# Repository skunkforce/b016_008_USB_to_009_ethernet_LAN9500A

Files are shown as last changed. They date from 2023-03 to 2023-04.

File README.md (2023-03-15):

# edgy_board number b016
This design is part of the [edgy board project](https://github.com/skunkforce/edgy_boards).

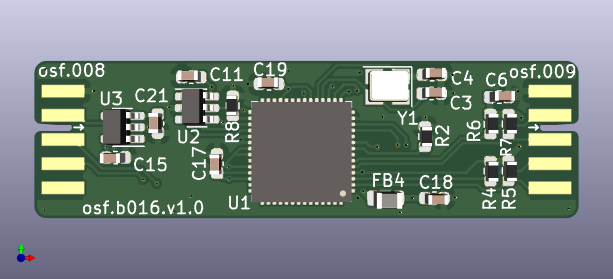
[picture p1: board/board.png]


# getting started
This repository uses submodules. After cloning use the command 

```$ git submodule update --init --recursive```

to pull the submodules before opening the project with kicad. 

# Tests
Tests can be found in [TESTS.md](TESTS.md)

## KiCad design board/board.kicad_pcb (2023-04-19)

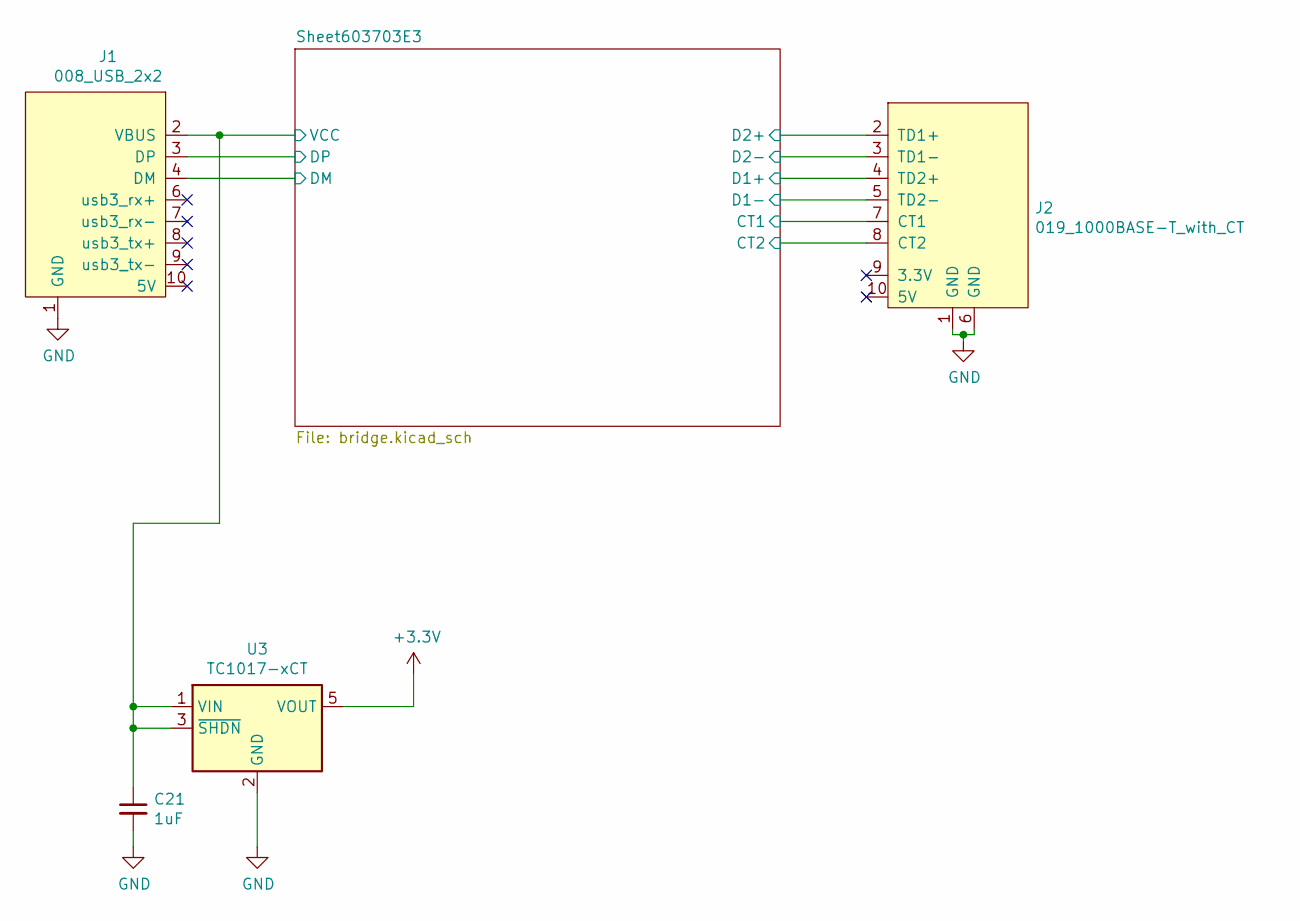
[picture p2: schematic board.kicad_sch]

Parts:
C21: 1uF; C_0603_1608Metric
J1: 008_USB_2x2; on_edge_2x05_device
J2: 019_1000BASE-T_with_CT; on_edge_2x05_host
U3: TC1017-xCT; SOT-23-5

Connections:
+3.3V: U3.5 (VOUT); also elsewhere on the board
/Sheet603703E3/CT1: J2.7 (CT1), J2.8 (CT2); also elsewhere on the board
/Sheet603703E3/D1+: J2.4 (TD2+); also elsewhere on the board
/Sheet603703E3/D1-: J2.5 (TD2-); also elsewhere on the board
/Sheet603703E3/D2+: J2.2 (TD1+); also elsewhere on the board
/Sheet603703E3/D2-: J2.3 (TD1-); also elsewhere on the board
/Sheet603703E3/DM: J1.4 (DM); also elsewhere on the board
/Sheet603703E3/DP: J1.3 (DP); also elsewhere on the board
/VCC: C21.1, J1.2 (VBUS), U3.1 (VIN), U3.3 (~SHDN)
GND: C21.2, J1.1 (GND), J2.1 (GND), J2.6 (GND), U3.2 (GND); also elsewhere on the board

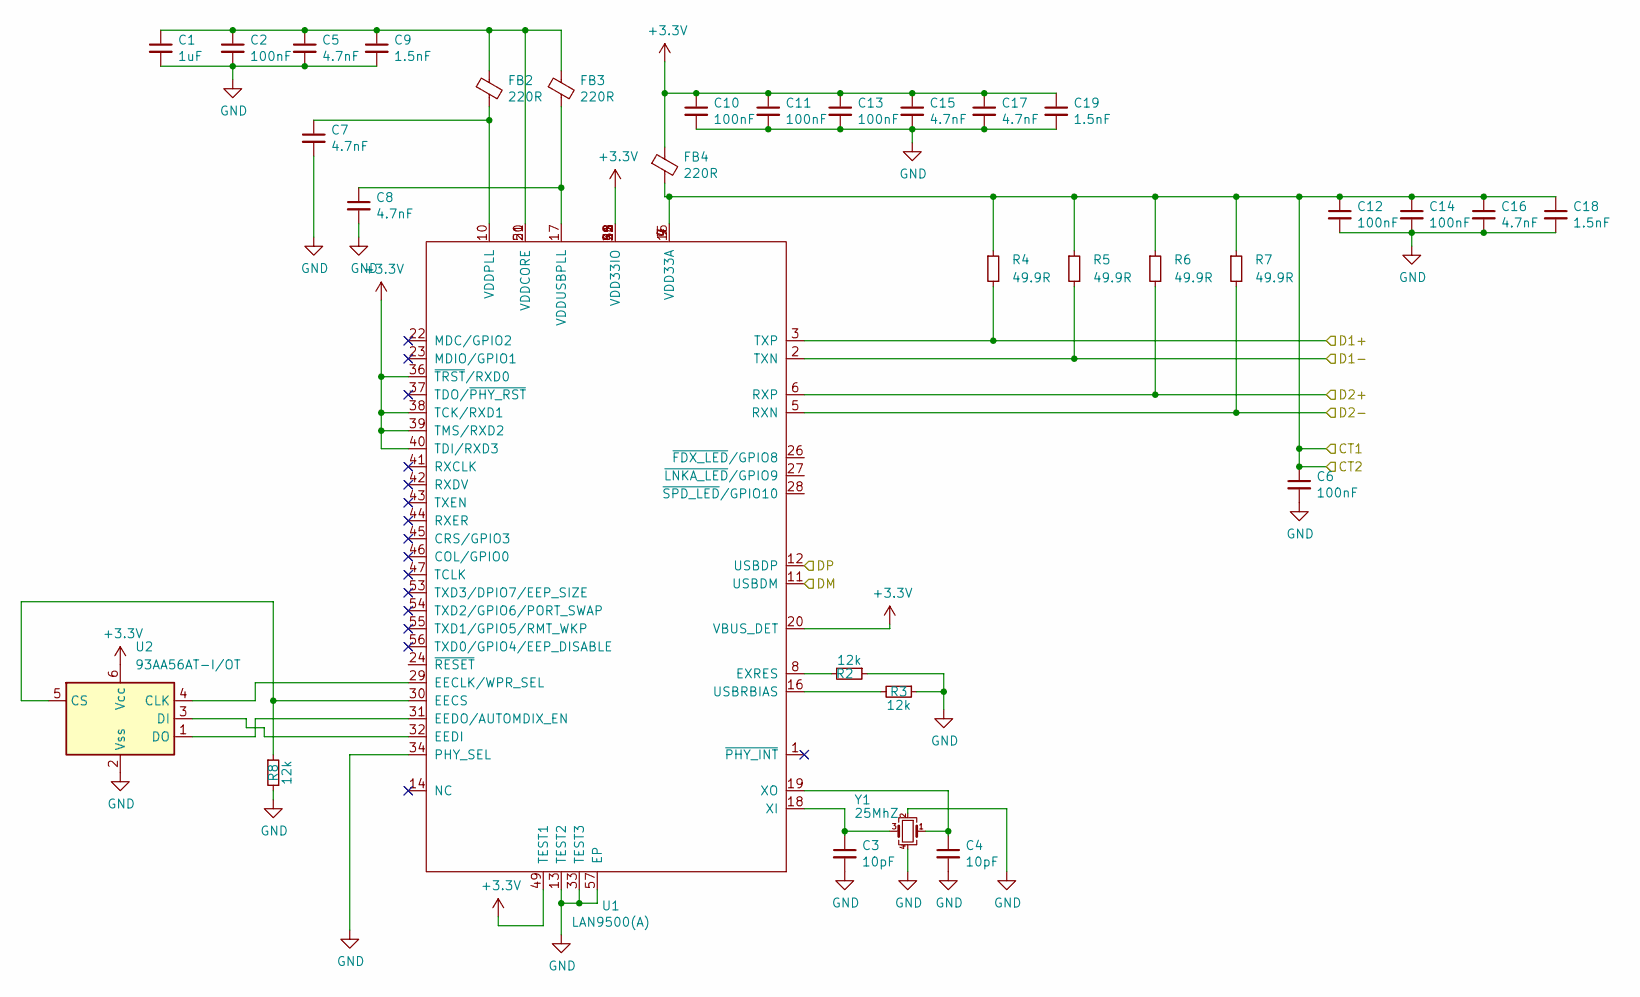
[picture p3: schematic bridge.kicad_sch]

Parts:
C1: 1uF; C_0603_1608Metric
C2, C6, C10, C11, C12, C13, C14: 100nF; C_0603_1608Metric
C3, C4: 10pF; C_0603_1608Metric
C5, C7, C8, C15, C16, C17: 4.7nF; C_0603_1608Metric
C9, C18, C19: 1.5nF; C_0603_1608Metric
FB2, FB3, FB4: 220R; L_0805_2012Metric
R2, R3, R8: 12k; R_0603_1608Metric
R4, R5, R6, R7: 49.9R; R_0603_1608Metric
U1: LAN9500(A); QFN-56-1EP_8x8mm_P0.5mm_EP4.5x5.2mm; MPN LAN9500A
U2: 93AA56AT-I/OT; SOT-23-6
Y1: 25MhZ; Crystal_SMD_Abracon_ABM8G-4Pin_3.2x2.5mm; MPN 535-9140-1-ND

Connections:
+3.3V: C10.1, C11.1, C13.1, C15.1, C17.1, C19.1, FB4.1, U1.20 (VBUS_DET), U1.25 (VDD33IO), U1.35 (VDD33IO), U1.36 (~TRST/RXD0), U1.38 (TCK/RXD1), U1.39 (TMS/RXD2), U1.40 (TDI/RXD3), U1.48 (VDD33IO), U1.49 (TEST1), U1.51 (VDD33IO), U1.52 (VDD33IO), U2.6 (Vcc); also elsewhere on the board
/Sheet603703E3/CT1: C6.1, C12.1, C14.1, C16.1, C18.1, FB4.2, R4.1, R5.1, R6.1, R7.1, U1.4 (VDD33A), U1.7 (VDD33A), U1.9 (VDD33A), U1.15 (VDD33A); also elsewhere on the board
/Sheet603703E3/D1+: R4.2, U1.3 (TXP); also elsewhere on the board
/Sheet603703E3/D1-: R5.2, U1.2 (TXN); also elsewhere on the board
/Sheet603703E3/D2+: R6.2, U1.6 (RXP); also elsewhere on the board
/Sheet603703E3/D2-: R7.2, U1.5 (RXN); also elsewhere on the board
/Sheet603703E3/DM: U1.11 (USBDM); also elsewhere on the board
/Sheet603703E3/DP: U1.12 (USBDP); also elsewhere on the board
GND: C1.2, C2.2, C3.2, C4.2, C5.2, C6.2, C7.2, C8.2, C9.2, C10.2, C11.2, C12.2, C13.2, C14.2, C15.2, C16.2, C17.2, C18.2, C19.2, R2.1, R3.1, R8.2, U1.13 (TEST2), U1.33 (TEST3), U1.34 (PHY_SEL), U1.57 (EP), U2.2 (Vss), Y1.2, Y1.4; also elsewhere on the board
unnamed: C1.1, C2.1, C5.1, C9.1, FB2.1, FB3.1, U1.21 (VDDCORE), U1.50 (VDDCORE)
unnamed: C3.1, U1.18 (XI), Y1.3
unnamed: C4.1, U1.19 (XO), Y1.1
unnamed: C7.1, FB2.2, U1.10 (VDDPLL)
unnamed: C8.1, FB3.2, U1.17 (VDDUSBPLL)
unnamed: R2.2, U1.8 (EXRES)
unnamed: R3.2, U1.16 (USBRBIAS)
unnamed: R8.1, U1.30 (EECS), U2.5 (CS)
unnamed: U1.29 (EECLK/WPR_SEL), U2.4 (CLK)
unnamed: U1.31 (EEDO/AUTOMDIX_EN), U2.1 (DO)
unnamed: U1.32 (EEDI), U2.3 (DI)

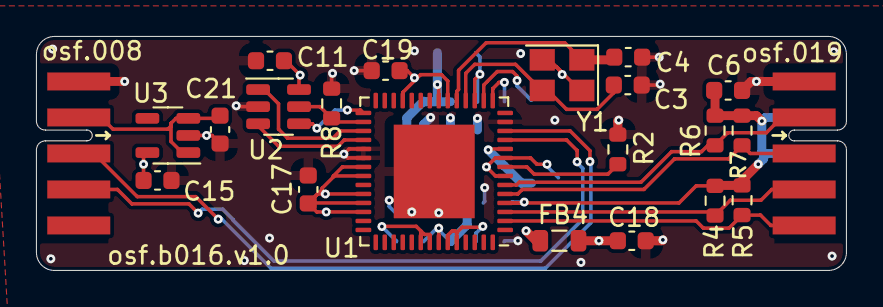
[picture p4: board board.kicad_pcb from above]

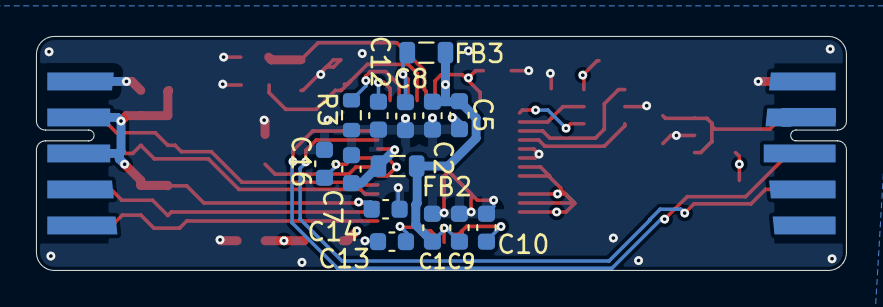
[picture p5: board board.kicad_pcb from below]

Board: 4 copper layers, 45.0 x 13.0 mm, 36 parts (14 on the bottom side), 21 nets.

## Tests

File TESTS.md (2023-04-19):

# communication test
## setup
```mermaid
graph LR
    USB --> b051 
    b051 --> b016 
    b016 --> b038
    b038 --> ethernet
```
## results
Computer connected to USB side was able to communicate with the internet connected to the ethernet side.

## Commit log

2023-03-18 initial hw
    [board.kicad_pcb, board.kicad_sch, bridge.kicad_sch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]
2023-04-19 changed osf.009 to osf.019 on silkscreen
    [board.kicad_pcb, board.kicad_sch]
